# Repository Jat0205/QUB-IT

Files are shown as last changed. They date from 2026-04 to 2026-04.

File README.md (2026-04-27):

# QUB-IT
QUB-IT: A Quantum Bop It Game <br><br>
**Contributors:** <br>
Jessica Huang, UPitt EE<br>
Thomas Eble, UPitt EPhys<br>
Jannet Trabelsi, UPitt EPhys<br><br>
**Microcontroller:** <br> 
atmega328p <br><br>
**Programming Language:** <br>
C++<br><br>
**Pinout:** <br>
DO 0:Y ROT ENC <br>
DO 1: LED |+>  <br>
DO 2: X ROT ENC <br>
DO 3: LED |0> <br>
DO 4: AUDIO <br>
DO 5: AUDIO <br>
DO 6: LED |-> <br>
DO 7: Z ROT ENC <br>
DO 8: DEBUG LED <br>
DO 9: LED |1> <br>
DO 10: LED |i> <br>
DO 11: LED |-i> <br>
DO 12: <br>
DO 13: <br>
A0: BUTTON: Measure Z <br>
A1: BUTTON: Measure Y <br>
A2: BUTTON: Measure X <br>
A3:PHOTODIODE <br>
A4: LCD <br>
A5: LCD <br><br>

** Steps to reproduce our work:<br>
- Refer to the provided schematic to reproduce the work and test it on a breadboard first.<br>
- Order the PCB included through JLCPCB (we used their design rule check.<br>
- Order parts needed from digikey, amazon, thorlabs, and JBsuperstore (BOM is provided).<br>
- Solder PCB.<br>
- 3D print sphere, sphere stand, and remote enclosure (stl files included).<br>
- place the LEDs and photodiode in the sphere such as the LEDs on the same axis correspond to the same basis.<br>
- Connect the wires from the sphere to the wires soldered on the PCB (color code them for easier debugging)<br>
- Add the provided audio files in a micro SD card. <br>
- Attach the SD card to the DF player. <br>
- Connect a usbtiny Program the 6 pin area on the PCB and load the Qubit_Main.ino file into ardiino IDE, burn the bootloader, compile the program, export the compiled library, then program the board. if you have mac, open a terminal at folder then paste the following: avrdude -c usbtiny -p m328p -P usb -e -U flash:w:/Users/USERNAME/Documents/Arduino/Qubit_Main/build/arduino.avr.uno/Qubit_Main.ino.hex (please replace USER by your username).<br>
- Connect a 9 V battery and use the switch to turn on the toy. (the reset button can also be used to reset the game). <br>
- Enjoy Qub-it!<br>

Please note: there are multiple ino files to test individual functions and debug your PCB, such as LCD.ino, MEASURE_IT.ino, ROT_ENC.ino, STATE_TRANSITION.ino, audio_test.ino, and photodiode.ino. Each file tests an individual function.<br> 
The file named "finding_out_audio_names.ino" displays the file name recognized on the DF player on the LCD so you can go to the Qubit_Main.ino and edit this part with the corresponding numbers:<br>
// ================= DFPlayer TRACK MAP =================<br>
const int TRACK_INIT    = 7;<br>
const int TRACK_X       = 10;<br>
const int TRACK_Y       = 8;<br>
const int TRACK_Z       = 4;<br>
const int TRACK_MEASURE = 2;<br>
const int TRACK_STARTUP = 1;<br>

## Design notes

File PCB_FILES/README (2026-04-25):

Please submit this with JLCPCB to order a PCB for yourself.

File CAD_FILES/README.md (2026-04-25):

Please upload the SLT files to ultimaker CURA and choose your printer speed and support then export the gcode files then 3D print the enclosures.

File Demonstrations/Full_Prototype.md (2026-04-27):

Here is the link to the full prototype video: https://youtu.be/gmHKGlXtQ_0

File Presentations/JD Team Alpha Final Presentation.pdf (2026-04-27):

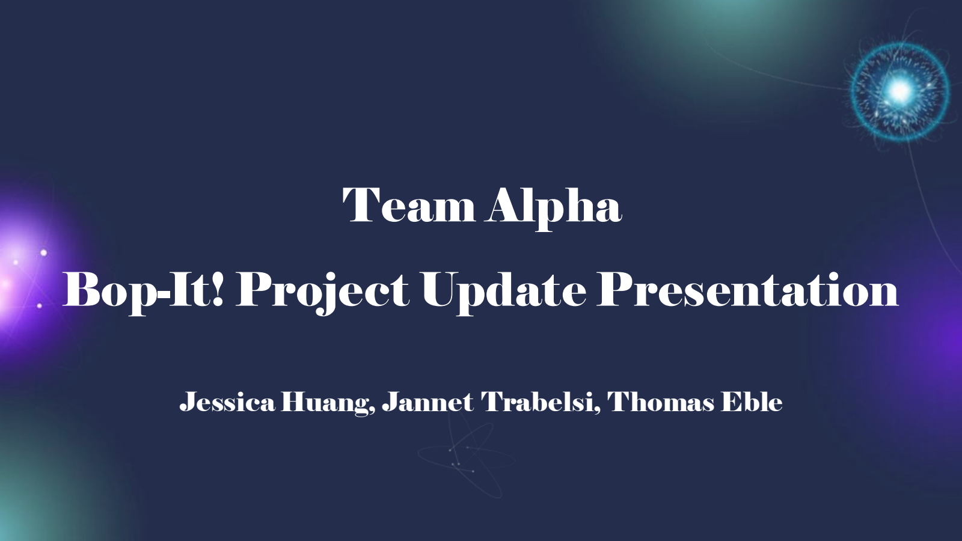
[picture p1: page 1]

# Team Alpha

# Bop-It! Project Update Presentation

### Jessica Huang, Jannet Trabelsi, Thomas Eble

# Our version of Bop-It….Qub-It!

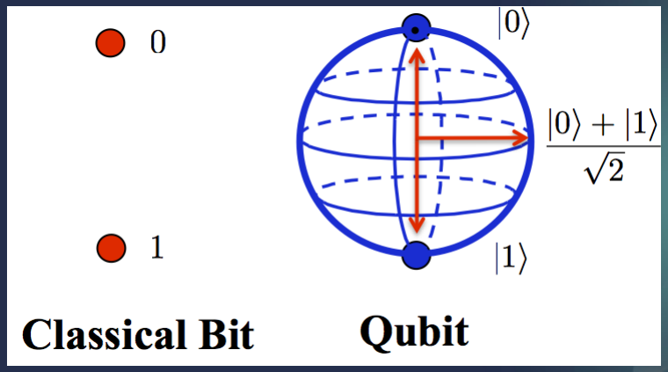
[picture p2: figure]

Brief review of how a qubit works:

A qubit is like a spinning arrow (or coin):

- - Unlike a normal bit, it can be 0, 1, 0r both at

once (superposition)

- Quantum gates rotate that arrow to control the

qubit’s state in 3D space in the x,y,z axes.

- When you measure, it collapses to either 0 or 1.
- Over time, noise can interfere, causing

decoherence

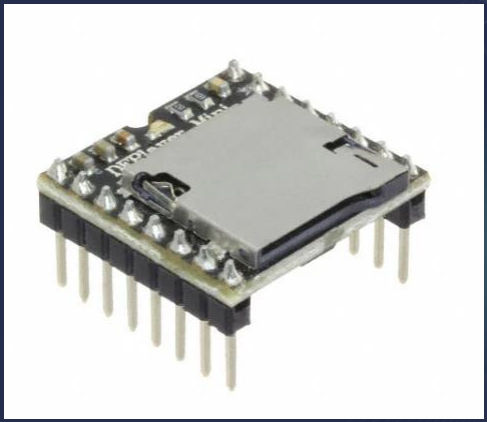
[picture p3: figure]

# Status Update

The DF-Player draws too much

current!

Our (2nd) PCB does not have the

proper power distribution to

handle high current draw.

A DF boot failure causes the rest

of our code to not function

properly

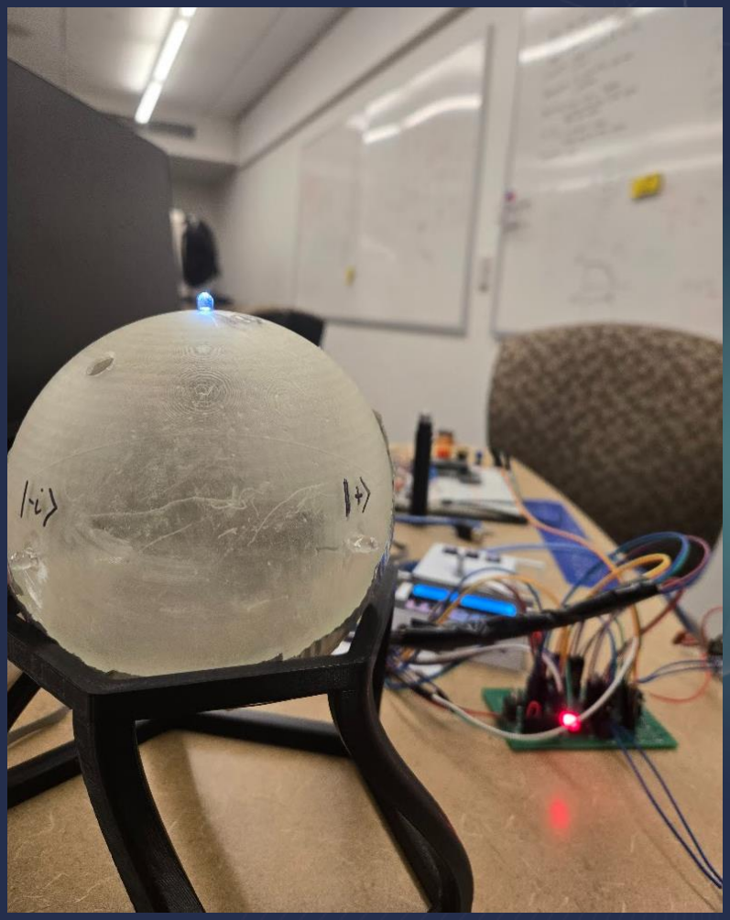
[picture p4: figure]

# Status Update

Our enclosure demonstrates gating and

measurement state transition functionality

However, our complete QUB-IT protocol only

functions at the breadboard phase!

# Future Work

- Third PCB redesign with appropriate power distribution

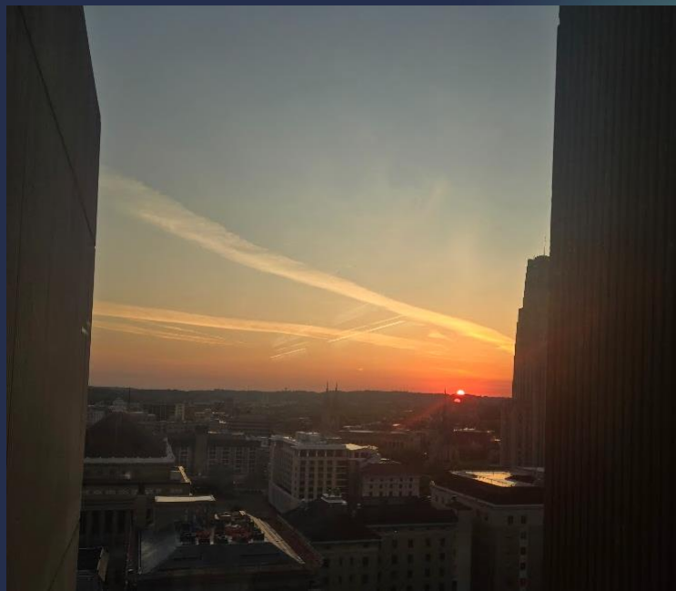
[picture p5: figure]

- Further enclosure iterations
- More ergonomic
- Fits new PCB
- Snap-fit
- Resin print lid
- New sphere with better diameter tolerance

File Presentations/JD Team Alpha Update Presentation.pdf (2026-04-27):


# Team Alpha

# Bop-It! Project Update Presentation

Jessica Huang, Jannet Trabelsi, Thomas Eble

What is a Qubit? | Z Measurement

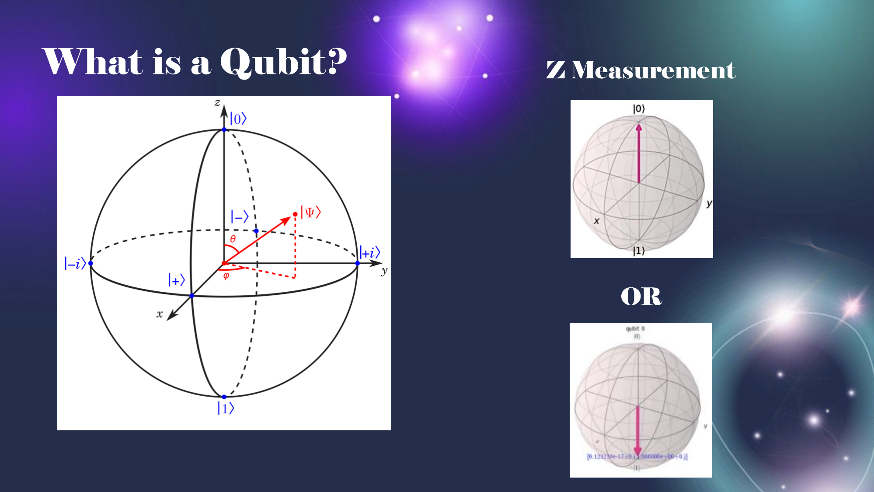
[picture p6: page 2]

OR

## What is a Qubit?

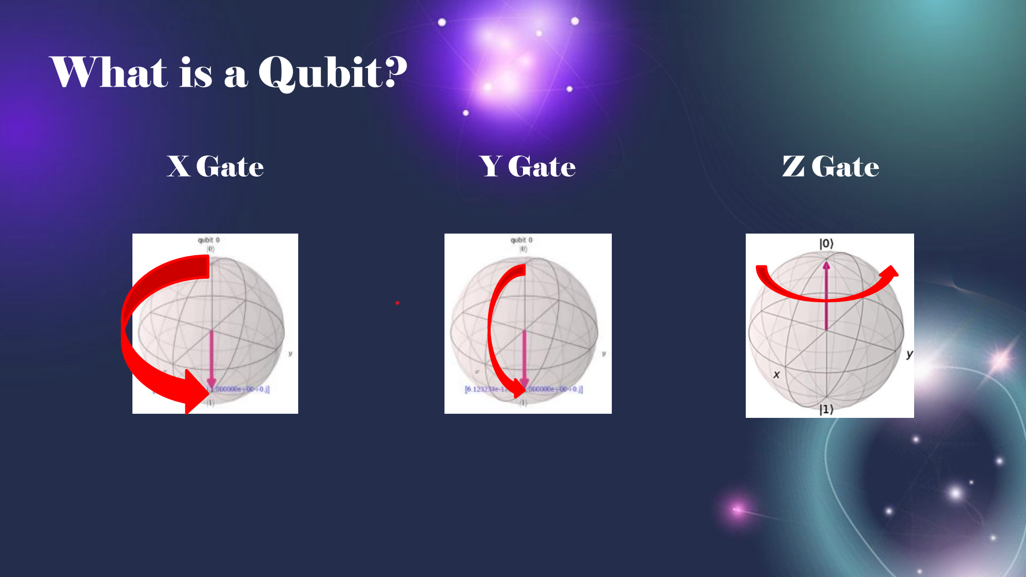
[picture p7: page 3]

X Gate | Y Gate | Z Gate

## Our version of Bop-It….Qub-It!

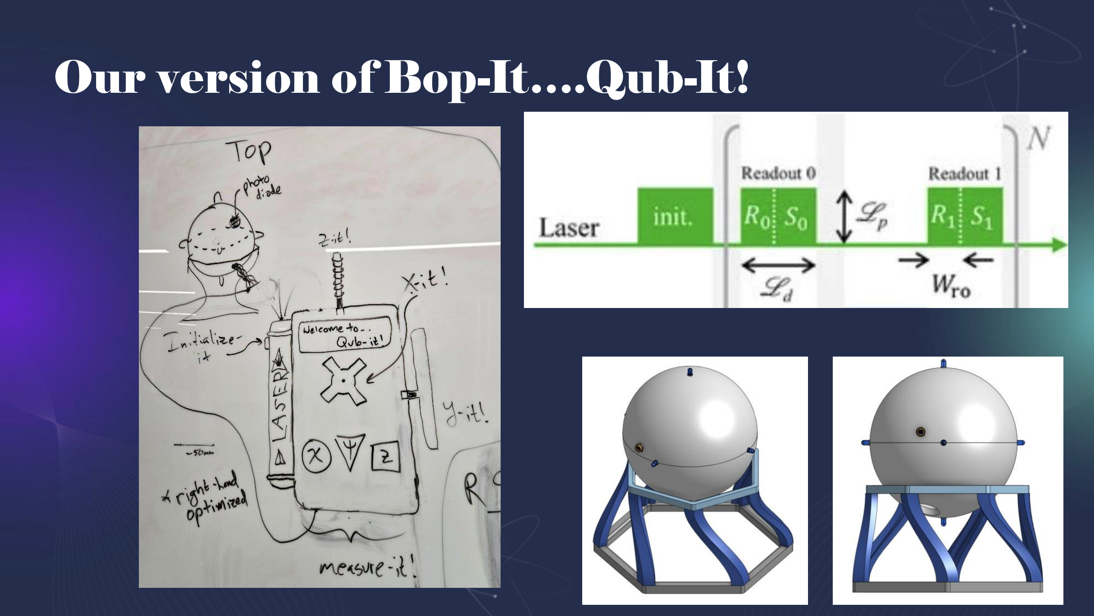
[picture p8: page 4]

## Progress (Start to Now)

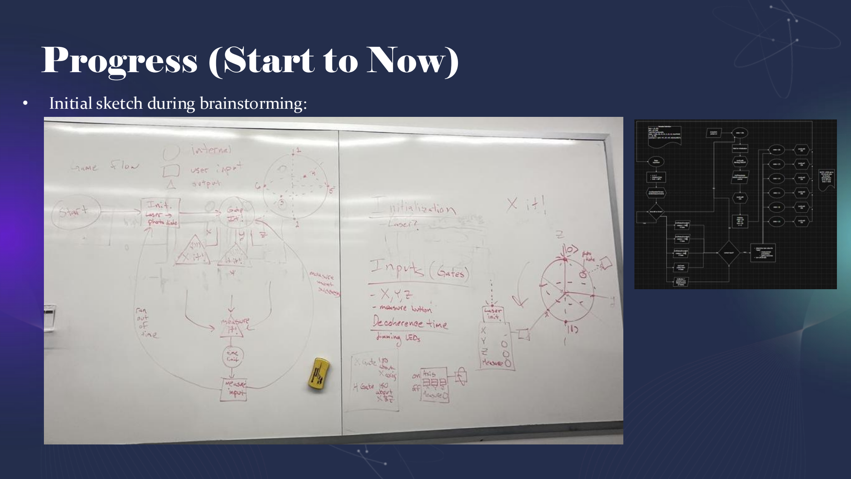
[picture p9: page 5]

- Initial sketch during brainstorming:

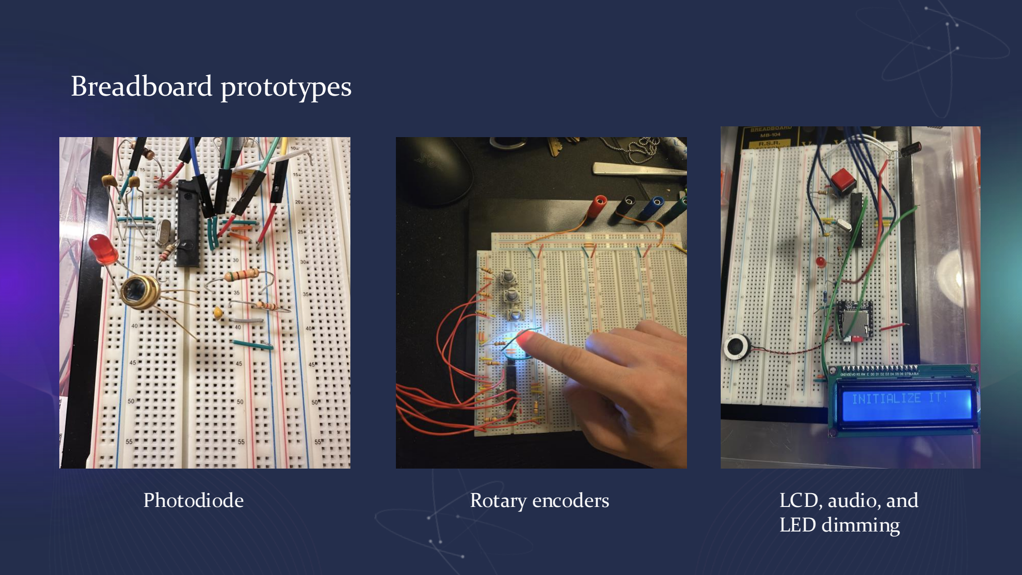
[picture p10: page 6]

Photodiode | Rotary encoders

Breadboard prototypes

LCD, audio, and
LED dimming

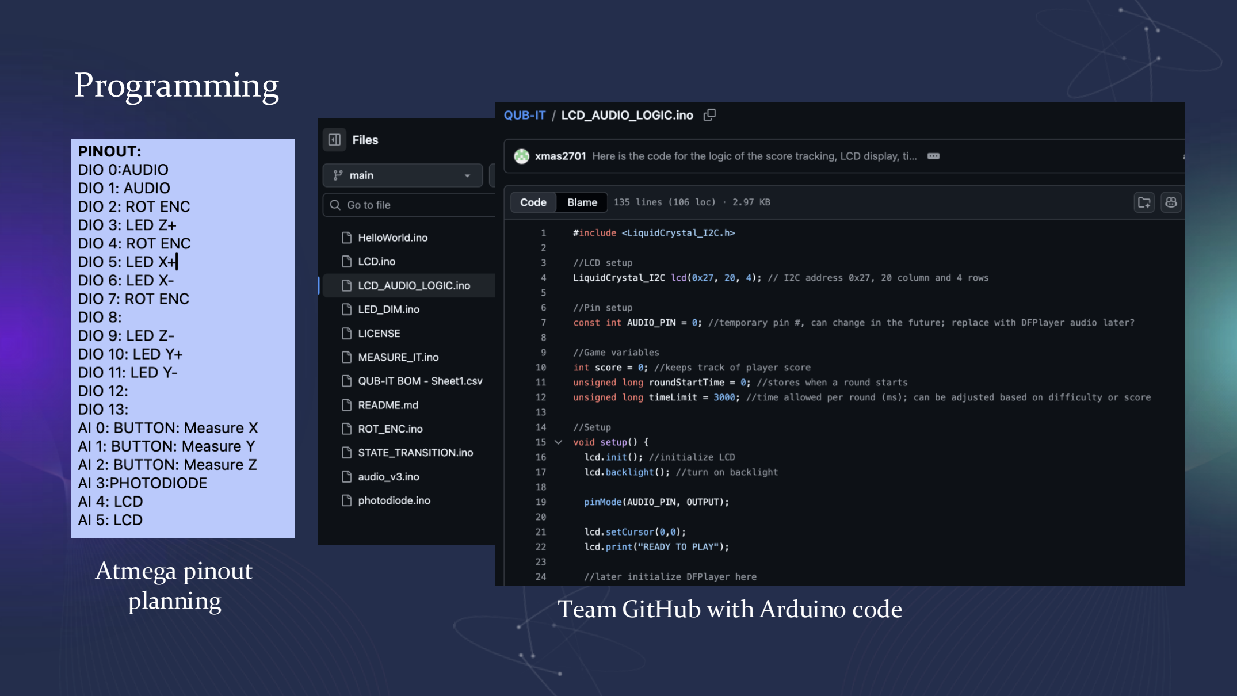
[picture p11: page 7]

Atmega pinout
planning | Team GitHub with Arduino code

Programming

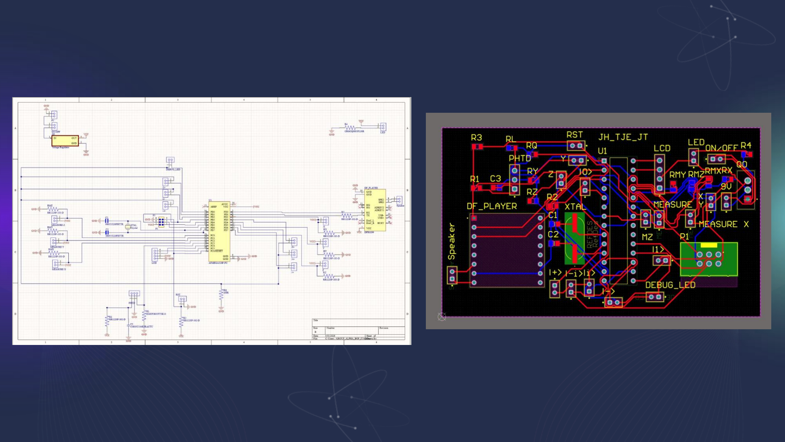
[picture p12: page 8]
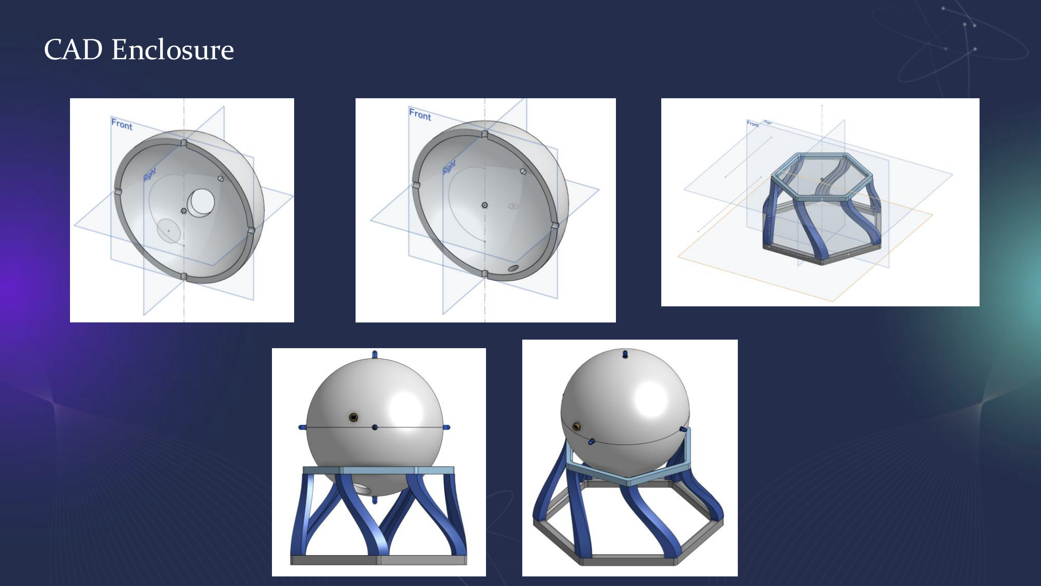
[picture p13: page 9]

CAD Enclosure

## What we still need to work on…

- Design PCB enclosure/main Bop-It toy
- Combine gating logic with dimming logic and Bop-It game functionality
- Solder PCB
- Assemble QUB-IT!
- If time permitting...
- Enclosure improvements: better aesthetics, stronger plastic/resin
- Addition of an H gate and the various code and board adjustments that come with it

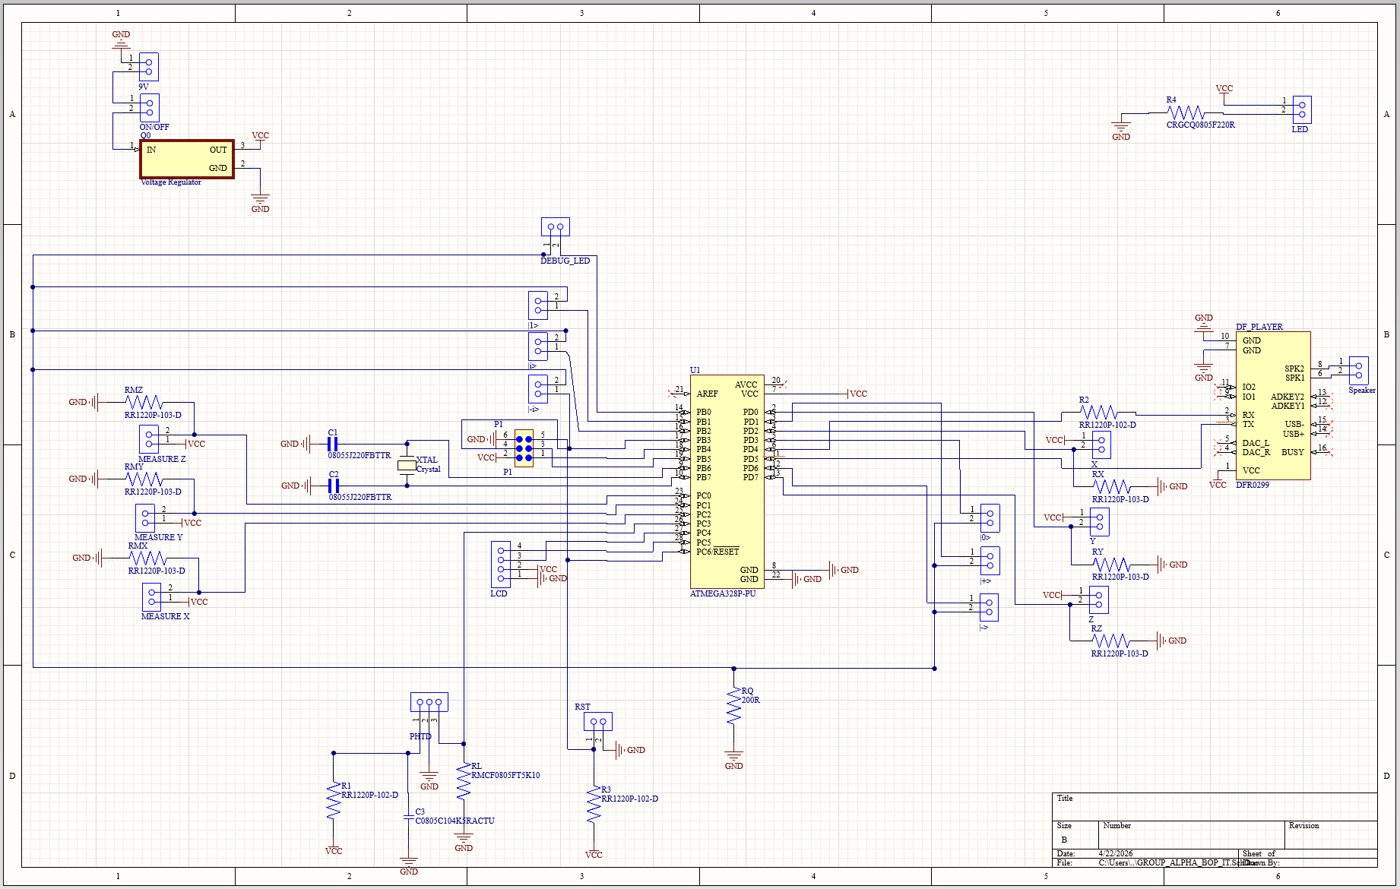
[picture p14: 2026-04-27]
PCB_FILES/SCHEMATIC.png

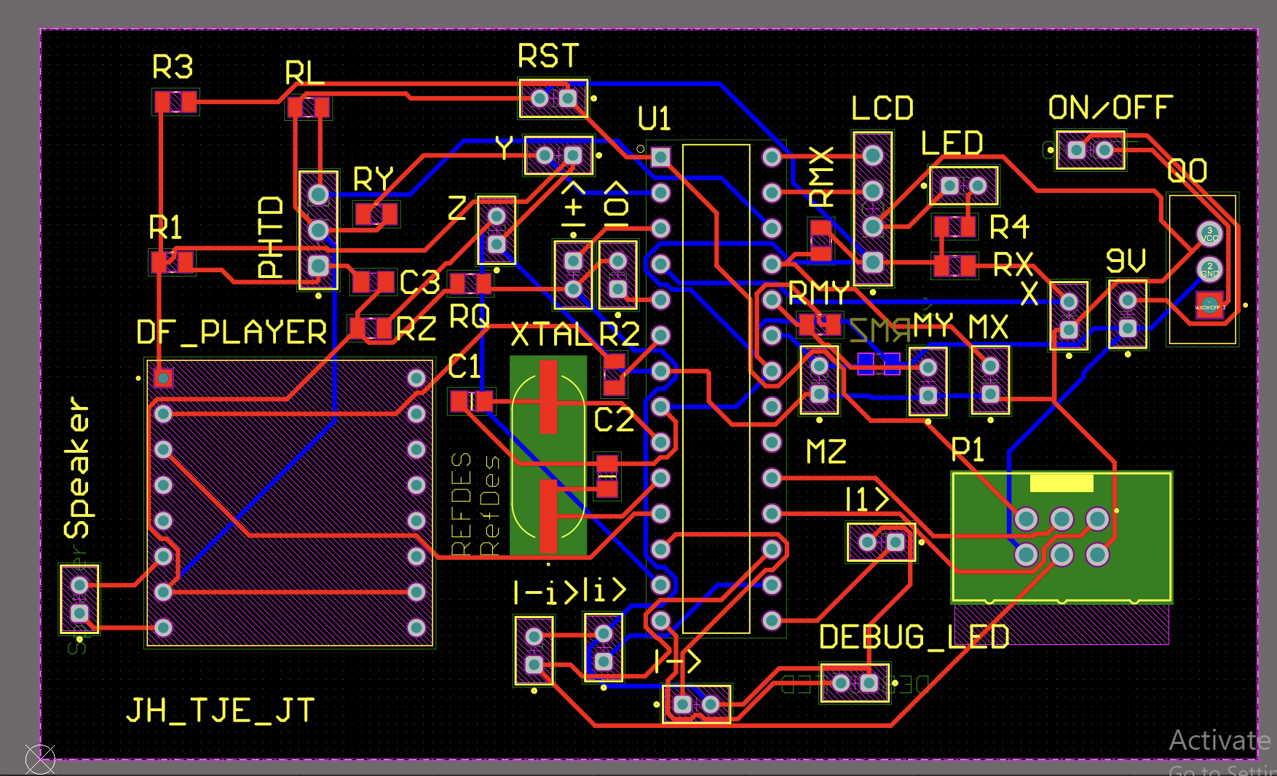
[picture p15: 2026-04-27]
PCB_FILES/PCB_Screenshot.png

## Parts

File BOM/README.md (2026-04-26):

Please order the following: <br>
- Photodiode: https://www.thorlabs.com/item/FDS100 $17.55 <br>
- LCD: https://jbsuperstore.com/products/Display-20x4-LCD-Screen-I2C-p799723774 $9.98<br>
- USBtinyISP Programmer: https://everymarket.com/products/usbtiny-usbtinyisp-avr-usb-tiny-isp-programmer-bootloader-with-programming-cable <br>
- Laser pointer: https://www.amazon.com/Advanced-Long-Range-Laser-Pointer-Power/dp/B0DP9G71M2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 $9.98<br>
- DF player: https://jbsuperstore.com/products/DFPlayer-Mini-MP3-Player-TF-MicroSD-card-compatible-p777890314 $5.90 <br>
- Dijikey: (please upload the CSV to dijikey and order the parts) :$41.75<br>
Total Cost = $17.55+ $9.98+ $9.98 + $5.90+ $98.10 = $141.51 <br>

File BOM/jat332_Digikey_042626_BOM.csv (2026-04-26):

Index | Quantity | Part Number | Manufacturer Part Number | Description | Customer Reference | Available | Backorder | Unit Price | Extended Price USD
1 | 1 | 732-5394-ND | 61200621621 | CONN HEADER VERT 6POS 2.54MM | jat332 | 1 | 0 | 0.48000 | 0.48
2 | 1 | 300-6134-1-ND | HCM4916000000ABJT | CRYSTAL 16.0000MHZ 18PF SMD | jat332 | 1 | 0 | 0.44000 | 0.44
3 | 2 | 478-11911-1-ND | 08055J220FBTTR | CAP THIN FILM 22PF 50V 0805 | jat332 | 2 | 0 | 1.90000 | 3.80
4 | 1 | 399-C0805C104K5RACTUCT-ND | C0805C104K5RACTU | CAP CER 0.1UF 50V X7R 0805 | jat332 | 1 | 0 | 0.13000 | 0.13
5 | 3 | RMCF0805FT5K10CT-ND | RMCF0805FT5K10 | RES 5.1K OHM 1% 1/8W 0805 | jat332 | 3 | 0 | 0.10000 | 0.30
6 | 1 | RR12P10.0KDCT-ND | RR1220P-103-D | RES SMD 10K OHM 0.5% 1/10W 0805 | jat332 | 1 | 0 | 0.10000 | 0.10
7 | 1 | RR12P1.0KDCT-ND | RR1220P-102-D | RES SMD 1K OHM 0.5% 1/10W 0805 | jat332 | 1 | 0 | 0.10000 | 0.10
8 | 1 | ATMEGA328-PU-ND | ATMEGA328-PU | IC MCU 8BIT 32KB FLASH 28DIP | jat332 | 1 | 0 | 2.63000 | 2.63
9 | 8 | 160-1142-ND | LTL-4231N | LED GREEN DIFFUSED T/H | jat332 | 8 | 0 | 0.15000 | 1.20
10 | 4 | EG2041-ND | PS1057ABLK | SWITCH PUSH SPST-NO 1A 125V | jat332 | 4 | 0 | 1.76000 | 7.04
11 | 1 | RA11131100-ND | RA11131100 | SWITCH ROCKER SPST 10A 125V | jat332 | 1 | 0 | 0.64000 | 0.64
12 | 1 | 497-1443-5-ND | L7805CV | IC REG LINEAR 5V 1.5A TO220 | jat332 | 1 | 0 | 0.50000 | 0.50
13 | 1 | P687-ND | 6LF22XWA/B | BATTERY ALKALINE 9V | jat332 | 1 | 0 | 2.32000 | 2.32
14 | 1 | 36-233-ND | 233 | BATT CONNECTOR SNAP 9V 6" LEADS | jat332 | 1 | 0 | 0.58000 | 0.58
15 | 1 | 433-1150-ND | SP-3605 | SPEAKER 8OHM 1W TOP PORT 90DB | jat332 | 1 | 0 | 3.62000 | 3.62
16 | 1 | 2084-SQF-MSDS1-256M-21E-ND | SQF-MSDS1-256M-21E | SQF MICRO SD C6 SLC 256M, 1CH (- | jat332 | 0 | 1 | 9.98000 | 9.98
17 | 1 | 2057-ICM-328-1-GT-HT-ND | ICM-328-1-GT-HT | MACHINE PIN SOCKET, IC, DIP, 28P | jat332 | 1 | 0 | 1.28000 | 1.28
18 | 1 | 72-T0051404699-ND | T0051404699 | WSW SCN M1 SN0,6CU0,05NI3,5% | jat332 | 1 | 0 | 21.82000 | 21.82
19 | 1 | K617-ND | R30G-0100 | WIRE WW 30AWG PVDF GREEN 100' | jat332 | 1 | 0 | 24.86000 | 24.86
20 | 3 | PEC11R-4220K-S0024-ND | PEC11R-4220K-S0024 | ENCODER INCREM QUAD VERT PC PIN | jat332 | 3 | 0 | 2.27000 | 6.81

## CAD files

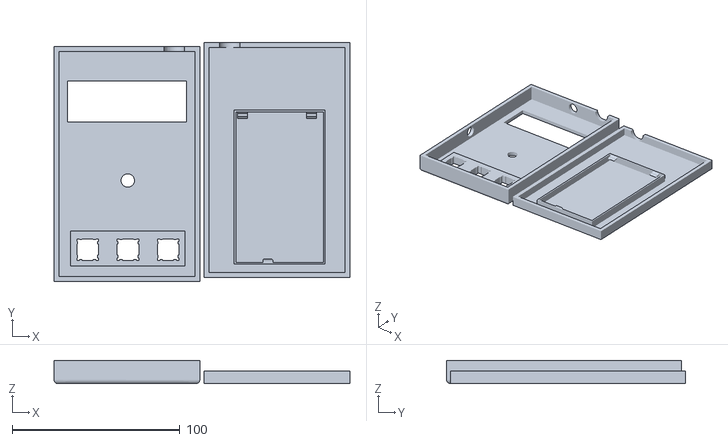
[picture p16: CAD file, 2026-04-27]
CAD_FILES/QUBIT_main_v9.stl
176.5 x 142.5 x 14.0

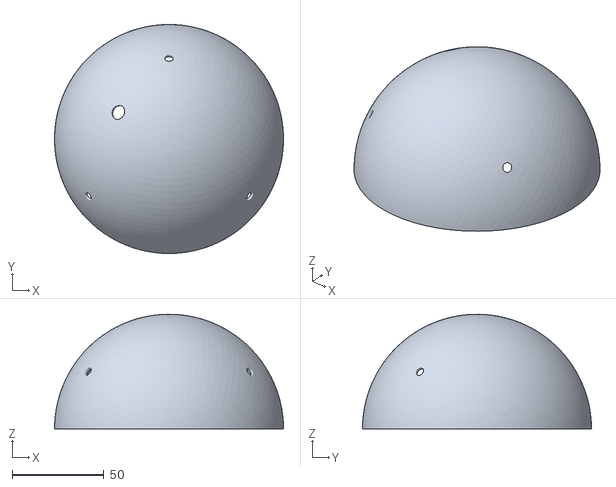
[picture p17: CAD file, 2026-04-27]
CAD_FILES/QUBIT_pdsphere_v3.stl
125.0 x 125.0 x 62.5

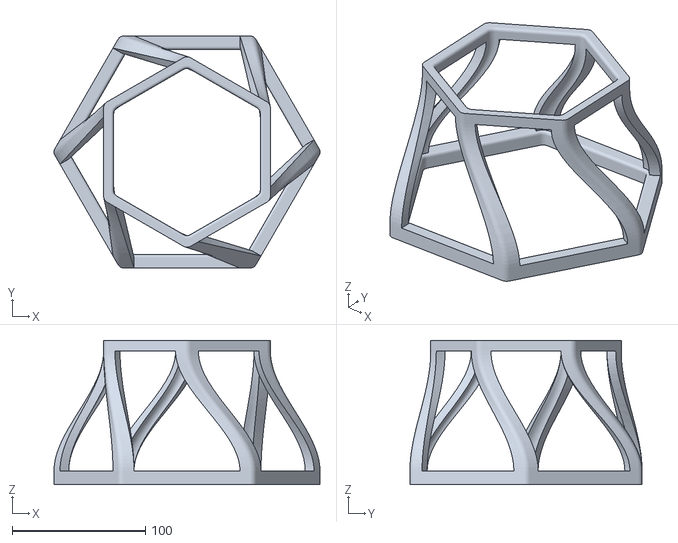
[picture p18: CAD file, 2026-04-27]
CAD_FILES/QUBIT_stand_v1.stl
199.7 x 174.3 x 108.5

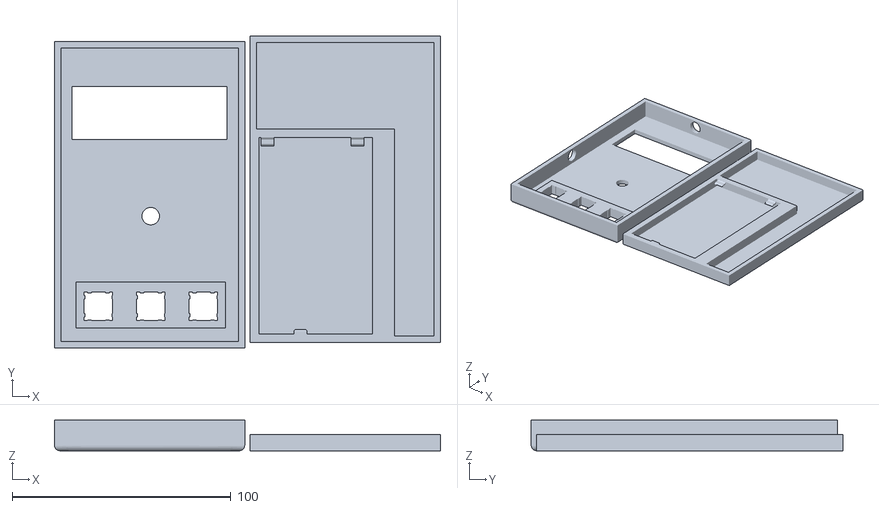
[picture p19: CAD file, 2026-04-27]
CAD_FILES/QUBIT_Lid_v5.stl
176.5 x 142.5 x 14.0

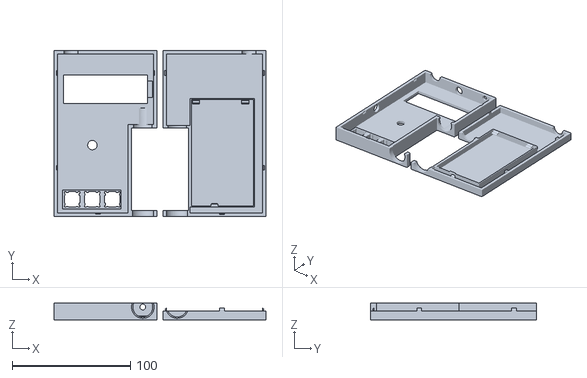
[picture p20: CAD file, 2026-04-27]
CAD_FILES/QUBIT_enclosure_v20.stl
179.0 x 140.0 x 14.0

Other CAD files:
CAD_FILES/QUBIT_csphere_v3.stl

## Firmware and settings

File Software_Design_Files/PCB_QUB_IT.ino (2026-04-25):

// ================================================================
//  QUB-IT  —  A Quantum Bop-It Game
// ================================================================

#include "Arduino.h"
#include <LiquidCrystal_I2C.h>
#include "DFRobotDFPlayerMini.h"

// ================= SOFT SERIAL FOR DFPLAYER =================
#if (defined(ARDUINO_AVR_UNO) || defined(ESP8266))
#include <SoftwareSerial.h>
SoftwareSerial softSerial(/*rx =*/4, /*tx =*/5);
#define FPSerial softSerial
#else
#define FPSerial Serial1
#endif

DFRobotDFPlayerMini myDFPlayer;

// ================= LCD =================
LiquidCrystal_I2C lcd(0x27, 20, 4);

// ================= PIN DEFINITIONS =================
const int ROTENCX    = 2;
const int ROTENCY    = 0;
const int ROTENCZ    = 7;
const int DEBUGLED   = 8;
const int PHOTODIODE = A3;
const int MEASUREX   = A2;
const int MEASUREY   = A1;
const int MEASUREZ   = A0;

const int LED_PINS[6] = {
  3,   // index 0 → |0>   (PWM)
  9,   // index 1 → |1>   (PWM)
  1,   // index 2 → |+>   (digital only)
  6,   // index 3 → |->   (PWM)
  10,  // index 4 → |i>   (PWM)
  11   // index 5 → |-i>  (PWM)
};

// ================= QUBIT PHYSICS ENGINE =================
int qubitState = 0;

const int NUM_OPS    = 8;
const int NUM_STATES = 6;
const int state_transition[NUM_OPS][NUM_STATES] = {
  {0, 0, 0, 0, 0, 0},
  {1, 0, 2, 3, 5, 4},
  {1, 0, 3, 2, 4, 5},
  {0, 1, 3, 2, 5, 4},
  {2, 3, 0, 1, 5, 4},        // H (unused)
  {-1, -1, 2, 3, -1, -1},
  {-2, -2, -2, -2, 4, 5},
  {0, 1, -3, -3, -3, -3},
};

int collapse_it(int state) {
  int coin = TCNT0 & 1;
  if (state == -1) return (coin == 0) ? 2 : 3;
  if (state == -2) return (coin == 0) ? 4 : 5;
  if (state == -3) return (coin == 0) ? 0 : 1;
  return state;
}

// ================= ENCODER GLOBALS =================
volatile int encX = 0, encY = 0, encZ = 0;
int lastStateX = LOW, lastStateY = LOW, lastStateZ = LOW;

// ================= GAME STATE MACHINE =================
enum GameState {
  GS_IDLE,
  GS_COMMAND,
  GS_WAIT_INPUT,
  GS_SUCCESS,
  GS_GAME_OVER
};
GameState gameState = GS_IDLE;

enum Command {
  CMD_INIT,
  CMD_X,
  CMD_Y,
  CMD_Z,
  CMD_MEASURE
};
Command currentCmd = CMD_INIT;

// Forward declarations
//void playCommand(Command cmd);
bool checkForWrongInput(Command cmd);
bool checkCorrectInput(Command cmd);
Command pickRandomCommand();
const char* commandText(Command cmd);

int  score           = 0;
int  dim_value       = 255;
bool ledOn           = false;
int  currentLedPin   = -1;

unsigned long roundStart    = 0;
unsigned long roundDuration = 10000;
const unsigned long MIN_ROUND_TIME = 2500;

const int ENCODER_THRESHOLD = 5;

// ================= DFPlayer TRACK MAP =================
const int TRACK_INIT    = 7;
const int TRACK_X       = 10;
const int TRACK_Y       = 8;
const int TRACK_Z       = 4;
const int TRACK_MEASURE = 2;
const int TRACK_STARTUP = 1;

// ================= DEBUG LED =================
void flashDebugLed() {
  digitalWrite(DEBUGLED, HIGH);
  delay(80);
  digitalWrite(DEBUGLED, LOW);
}

// ================= LED HELPERS =================
void ledWrite(int pin, int value) {
  if (pin == 1) {
    digitalWrite(pin, value > 127 ? HIGH : LOW);
  } else {
    analogWrite(pin, value);
  }
}

void allLedsOff() {
  for (int i = 0; i < 6; i++) {
    ledWrite(LED_PINS[i], 0);
  }
  ledOn = false;
  currentLedPin = -1;
}

void showQubitLed() {
  allLedsOff();
  currentLedPin = LED_PINS[qubitState];
  dim_value = 255;
  ledWrite(currentLedPin, 255);
  ledOn = true;
}

void dimLed() {
  if (!ledOn || currentLedPin < 0) return;
  unsigned long elapsed = millis() - roundStart;
  if (elapsed >= roundDuration) {
    dim_value = 0;
  } else {
    dim_value = map(elapsed, 0, roundDuration, 255, 0);
  }
  ledWrite(currentLedPin, dim_value);
  if (dim_value == 0) ledOn = false;
}

// ================= ENCODER POLLING =================
void pollEncoders() {
  int cx = digitalRead(ROTENCX);
  int cy = digitalRead(ROTENCY);
  int cz = digitalRead(ROTENCZ);

  if (cx == HIGH && lastStateX == LOW) encX++;
  lastStateX = cx;

  if (cy == HIGH && lastStateY == LOW) encY++;
  lastStateY = cy;

  if (cz == HIGH && lastStateZ == LOW) encZ++;
  lastStateZ = cz;
}

void resetEncoders() {
  encX = 0; encY = 0; encZ = 0;
}

// ================= SPEAKER =================
/*void playCommand(Command cmd) {
  switch (cmd) {
    case CMD_INIT:    myDFPlayer.play(TRACK_INIT);    break;
    case CMD_X:       myDFPlayer.play(TRACK_X);       break;
    case CMD_Y:       myDFPlayer.play(TRACK_Y);       break;
    case CMD_Z:       myDFPlayer.play(TRACK_Z);       break;
    case CMD_MEASURE: myDFPlayer.play(TRACK_MEASURE); break;
  }
}*/

// ================= LCD HELPERS =================
void lcdShowCommand(const char* text) {
  lcd.clear();
  lcd.setCursor(0, 0);
  lcd.print(text);
}

// ================= INPUT DETECTION =================
bool checkForWrongInput(Command cmd) {
  int mx = digitalRead(MEASUREX);
  int my = digitalRead(MEASUREY);
  int mz = digitalRead(MEASUREZ);
  int photo = analogRead(PHOTODIODE);
  bool laserHit = (photo >= 512);

  switch (cmd) {
    case CMD_INIT:
      if (mx == HIGH || my == HIGH || mz == HIGH) return true;
      if (encX > 2 || encY > 2 || encZ > 2) return true;
      break;
    case CMD_X:
      if (mx == HIGH || my == HIGH || mz == HIGH) return true;
      if (laserHit) return true;
      if (encY > ENCODER_THRESHOLD || encZ > ENCODER_THRESHOLD) return true;
      break;
    case CMD_Y:
      if (mx == HIGH || my == HIGH || mz == HIGH) return true;
      if (laserHit) return true;
      if (encX > ENCODER_THRESHOLD || encZ > ENCODER_THRESHOLD) return true;
      break;
    case CMD_Z:
      if (mx == HIGH || my == HIGH || mz == HIGH) return true;
      if (laserHit) return true;
      if (encX > ENCODER_THRESHOLD || encY > ENCODER_THRESHOLD) return true;
      break;
    case CMD_MEASURE:
      if (laserHit) return true;
      if (encX > 2 || encY > 2 || encZ > 2) return true;
      break;
  }
  return false;
}

bool checkCorrectInput(Command cmd) {
  switch (cmd) {
    case CMD_INIT: {
      int photo = analogRead(PHOTODIODE);
      if (photo >= 512) {
        qubitState = state_transition[0][qubitState];
        return true;
      }
      return false;
    }
    case CMD_X:
      if (encX >= ENCODER_THRESHOLD) {
        qubitState = state_transition[1][qubitState];
        return true;
      }
      return false;
    case CMD_Y:
      if (encY >= ENCODER_THRESHOLD) {
        qubitState = state_transition[2][qubitState];
        return true;
      }
      return false;
    case CMD_Z:
      if (encZ >= ENCODER_THRESHOLD) {
        qubitState = state_transition[3][qubitState];
        return true;
      }
      return false;
    case CMD_MEASURE: {
      int mx = digitalRead(MEASUREX);
      int my = digitalRead(MEASUREY);
      int mz = digitalRead(MEASUREZ);
      if (mx == HIGH) {
        qubitState = state_transition[5][qubitState];
        qubitState = collapse_it(qubitState);
        return true;
      }
      if (my == HIGH) {
        qubitState = state_transition[6][qubitState];
        qubitState = collapse_it(qubitState);
        return true;
      }
      if (mz == HIGH) {
        qubitState = state_transition[7][qubitState];
        qubitState = collapse_it(qubitState);
        return true;
      }
      return false;
    }
  }
  return false;
}

// ================= COMMAND GENERATION =================
Command pickRandomCommand() {
  int r = random(0, 5);
  switch (r) {
    case 0:  return CMD_INIT;
    case 1:  return CMD_X;
    case 2:  return CMD_Y;
    case 3:  return CMD_Z;
    default: return CMD_MEASURE;
  }
}

const char* commandText(Command cmd) {
  switch (cmd) {
    case CMD_INIT:    return "INITIALIZE IT!";
    case CMD_X:       return "X IT!";
    case CMD_Y:       return "Y IT!";
    case CMD_Z:       return "Z IT!";
    case CMD_MEASURE: return "MEASURE IT!";
  }
  return "";
}

// ================================================================
//  SETUP
// ================================================================
void setup() {
  lcd.init();
  lcd.backlight();
  lcd.clear();
  lcd.setCursor(0, 0);
  lcd.print("QUB-IT");
  lcd.setCursor(0, 1);
  lcd.print("Point laser to start");

  FPSerial.begin(9600);
  /*if (!myDFPlayer.begin(FPSerial, true, true)) {
    lcd.clear();
    lcd.print("DFPlayer FAIL");
    while (true);
  }
  myDFPlayer.setTimeOut(500);
  myDFPlayer.volume(30);
  myDFPlayer.EQ(DFPLAYER_EQ_NORMAL);
  myDFPlayer.outputDevice(DFPLAYER_DEVICE_SD);
  myDFPlayer.play(TRACK_STARTUP);*/

  pinMode(ROTENCX, INPUT);
  pinMode(ROTENCY, INPUT);
  pinMode(ROTENCZ, INPUT);
  pinMode(DEBUGLED, OUTPUT);
  pinMode(MEASUREX, INPUT);
  pinMode(MEASUREY, INPUT);
  pinMode(MEASUREZ, INPUT);
  for (int i = 0; i < 6; i++) {
    pinMode(LED_PINS[i], OUTPUT);
    ledWrite(LED_PINS[i], 0);
  }

  lastStateX = digitalRead(ROTENCX);
  lastStateY = digitalRead(ROTENCY);
  lastStateZ = digitalRead(ROTENCZ);
  randomSeed(analogRead(A5));

  gameState = GS_IDLE;
  qubitState = 0;
  score = 0;
}

// ================================================================
//  MAIN LOOP
// ================================================================
void loop() {
  pollEncoders();

  switch (gameState) {

    case GS_IDLE: {
      int photo = analogRead(PHOTODIODE);
      if (photo >= 512) {
        flashDebugLed();
        qubitState = 0;
        score = 0;
        roundDuration = 10000;
        allLedsOff();
        showQubitLed();
        score++;
        gameState = GS_SUCCESS;
      }
      break;
    }

    case GS_COMMAND: {
      currentCmd = pickRandomCommand();
      lcdShowCommand(commandText(currentCmd));
      //playCommand(currentCmd);
      resetEncoders();
      roundStart = millis();
      showQubitLed();
      gameState = GS_WAIT_INPUT;
      break;
    }

    case GS_WAIT_INPUT: {
      if (millis() - roundStart >= roundDuration) {
        gameState = GS_GAME_OVER;
        break;
      }
      dimLed();
      if (checkForWrongInput(currentCmd)) {
        flashDebugLed();
        gameState = GS_GAME_OVER;
        break;
      }
      if (checkCorrectInput(currentCmd)) {
        flashDebugLed();
        gameState = GS_SUCCESS;
      }
      break;
    }

    case GS_SUCCESS: {
      showQubitLed();
      lcd.clear();
      lcd.setCursor(0, 0);
      lcd.print("GOOD!");
      lcd.setCursor(0, 1);
      lcd.print("Score: ");
      lcd.print(score);

      if (score >= 99) {
        lcd.clear();
        lcd.setCursor(0, 0);
        lcd.print("VICTORY!");
        lcd.setCursor(0, 1);
        lcd.print("Final Score: 99");
        lcd.setCursor(0, 2);
        lcd.print("You are a quantum");
        lcd.setCursor(0, 3);
        lcd.print("master!");
        gameState = GS_GAME_OVER;
        break;
      }

      if (roundDuration > MIN_ROUND_TIME) {
        roundDuration -= 500;
        if (roundDuration < MIN_ROUND_TIME) {
          roundDuration = MIN_ROUND_TIME;
        }
      }

      delay(400);
      score++;
      gameState = GS_COMMAND;
      break;
    }

    case GS_GAME_OVER: {
      allLedsOff();
      lcd.clear();
      lcd.setCursor(0, 0);
      lcd.print("GAME OVER");
      lcd.setCursor(0, 1);
      lcd.print("Score: ");
      lcd.print(score);
      lcd.setCursor(0, 2);
      lcd.print("Laser to restart");

      while (true) {
        int photo = analogRead(PHOTODIODE);
        if (photo >= 512) {
          flashDebugLed();
          delay(500);
          break;
        }
      }

      qubitState = 0;
      score = 0;
      roundDuration = 10000;
      resetEncoders();
      allLedsOff();
      showQubitLed();
      score++;
      gameState = GS_SUCCESS;
      break;
    }
  }
}

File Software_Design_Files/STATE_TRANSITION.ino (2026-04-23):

// global variable definition
int r = 0; //number of rounds successfully passed
const int DIFFICULTY = 0; //difficulty integer which, when modified, changes the rate at which the game gets faster (when it is zero, every round is the same length)
int qubitState = 0; //current state of the qubit

//STATE TRANSITION LOOKUP TABLE
// transition[operation][current_state] = new_state
// operations:   0=intialize, 1=apply_x_gate, 2=apply_y_gate, 3=apply_z_gate 4=apply_h_gate, 5=perform_x_measurement, 6=perform_y_measurement, 7=perform_z_measurement
// States:  0=|0>, 1=|1>, 2=|+>, 3=|->, 4=|i>, 5=|-i>
const int NUM_OPS = 8;
const int NUM_STATES = 6;
const int state_transition[NUM_OPS][NUM_STATES] = {
  {0, 0, 0, 0, 0, 0},  // INIT: always |0>
  {1, 0, 2, 3, 5, 4},  // X: swap 0↔1, swap 4↔5, keep 2,3
  {1, 0, 3, 2, 4, 5},  // Y: swap 0↔1, swap 2↔3, keep 4,5
  {0, 1, 3, 2, 5, 4},  // Z: keep 0,1, swap 2↔3, swap 4↔5
  {2, 3, 0, 1, 5, 4},  // H: swap 0↔2, swap 1↔3, swap 4↔5
  {-1, -1, 2, 3, -1, -1},  // XMEAS: every -1 needs sep. function to collapse to 2 or 3
  {-2, -2, -2, -2, 4, 5},  // YMEAS: every -2 needs sep. function to collapse to 4 or 5
  {0, 1, -3, -3, -3, -3},  // ZMEAS: every -3 needs sep. function to collapse to 1 or 0
};


bool LEDS[NUM_STATES] = {false, false, false, false, false, false};
bool INIT_LED = false; //LED on the controller that flashes whn turned on and held on when qubit is initialized

//rot_enc globals
int x = 0;
int y = 0;
int z = 0;
int lastStateX = LOW;
int lastStateY = LOW;
int lastStateZ = LOW;

int coin = 0;


void setup() {
  pinMode(2, INPUT); //rot_encX
  pinMode(0, INPUT); //rot_encY
  pinMode(7, INPUT); //rot_encZ
  pinMode(8, OUTPUT);//output LED to verify rot_enc pulsing
  pinMode(A2, INPUT); //measure x button
  pinMode(A1, INPUT); //measure y button
  pinMode(A0, INPUT); //measure z button
  pinMode(3, OUTPUT); //|0> output
  pinMode(9, OUTPUT); //|1> output
  pinMode(1, OUTPUT); //|+> output
  pinMode(6, OUTPUT); //|-> output
  pinMode(10, OUTPUT); //|i> output
  pinMode(11, OUTPUT); //|-i> output
  lastStateX = digitalRead(2);
  lastStateY = digitalRead(0);
  lastStateZ = digitalRead(7);
  qubitState = 0;
}

void loop() {
  //rot_encX, Y, and Z, input detection
  detect_rotation();

  //state transitions for x, y, and z gate inputs
  detect_Xgate();
  detect_Ygate();
  detect_Zgate();

  //state transitions for x, y, and z measure inputs
  detect_Xmeasure();
  detect_Ymeasure();
  detect_Zmeasure();

  diode_output(qubitState);
}

void detect_Xmeasure(){
  int measureX = digitalRead(A2);
  if(measureX == HIGH){
    qubitState = state_transition[5][qubitState];
    qubitState = collapse_it(qubitState);
    digitalWrite(8, HIGH);
    delay(1000);
    digitalWrite(8, LOW);
  }
}

void detect_Ymeasure(){
  int measureY = digitalRead(A1);
  if(measureY == HIGH){
    qubitState = state_transition[6][qubitState];
    qubitState = collapse_it(qubitState);
    digitalWrite(8, HIGH);
    delay(1000);
    digitalWrite(8, LOW);
  }
}

void detect_Zmeasure(){
  int measureZ = digitalRead(A0);
  if(measureZ == HIGH){
    qubitState = state_transition[7][qubitState];
    qubitState = collapse_it(qubitState);
    digitalWrite(8, HIGH);
    delay(1000);
    digitalWrite(8, LOW);
  }
}

//function that takes the current state and returns an int corresponding to new state.
//should be called in main qubitState = collapse_it(qubitState)
int collapse_it(int qubitState){
  coin = TCNT0 & 1;
  if(qubitState == -1){
    if(coin == 0){
      return 2;
    }
    else{
      return 3;
    }
  }
  if(qubitState == -2){
    if(coin == 0){
      return 4;
    }
    else{
      return 5;
    }
  }
  if(qubitState == -3){
    if(coin == 0){
      return 1;
    }
    else{
      return 0;
    }
  }
  return qubitState;
}

void detect_rotation(){
  int currentStateX = digitalRead(2);
  int currentStateY = digitalRead(0);
  int currentStateZ = digitalRead(7);
  if (currentStateX == HIGH && lastStateX == LOW) {
    x++;
  }
  lastStateX = currentStateX;
  
  if (currentStateY == HIGH && lastStateY == LOW) {
    y++;
  }
  lastStateY = currentStateY;
  
  if (currentStateZ == HIGH && lastStateZ == LOW) {
    z++;
  }
  lastStateZ = currentStateZ;
}

//function detects x gate and adjusts state accordingly
void detect_Xgate(){
 if(x == 5){
    qubitState = state_transition[1][qubitState];
    digitalWrite(8, HIGH);
    delay(1000);
    digitalWrite(8, LOW);
    x = 0;
  } 
}

//function detects y gate and adjusts state accordingly
void detect_Ygate(){
  if(y == 5){
    qubitState = state_transition[2][qubitState];
    digitalWrite(8, HIGH);
    delay(1000);
    digitalWrite(8, LOW);
    y= 0;
  }
}

//function detects z gate and adjusts state accordingly
void detect_Zgate(){
 if(z == 5){
    qubitState = state_transition[3][qubitState];
    digitalWrite(8, HIGH);
    delay(1000);
    digitalWrite(8, LOW);
    z = 0;
  }
}

void diode_output(int qubitState){
  digitalWrite(3, LOW);
  digitalWrite(9, LOW);
  digitalWrite(1, LOW);
  digitalWrite(6, LOW);
  digitalWrite(10, LOW);
  digitalWrite(11, LOW);
  switch (qubitState){
    case 0:
      digitalWrite(3, HIGH);
      break;
    case 1:
      digitalWrite(9, HIGH);
      break;
    case 2:
      digitalWrite(1, HIGH);
      break;
    case 3:
      digitalWrite(6, HIGH);
      break;
    case 4:
      digitalWrite(10, HIGH);
      break;
    case 5:
      digitalWrite(11, HIGH);
      break;
  }
}

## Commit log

2026-03-22 Dummy LED dimming example
2026-03-23 Rotary Encoder Signal Processing and Output Test
2026-03-23 Update STATE_TRANSITION.ino
    added measure x, y, z input buttons
2026-03-23 added output LEDs
2026-03-24 fixed duplicate measurement bug: now repeated measurement leaves the qubit unchanged
    [STATE_TRANSITION.ino]
2026-03-24 state transition table accidentally swapped z state when performing repeated z measurements
    [STATE_TRANSITION.ino]
2026-03-24 Here is the code for the logic of the score tracking, LCD display, timer, and audio output.
    The audio portion of the code is mainly placeholders, and it will be updated once we figure out the DFPlayer/whatever audio module we use.
2026-03-24 Hello World blinking LEDs for GitHub Assignment
2026-03-30 QUB-IT BOM
    [QUB-IT BOM - Sheet1.csv]
2026-03-31 Revise component quantities in BOM
    Updated quantities for various components in the BOM.
    [QUB-IT BOM - Sheet1.csv]
2026-03-31 Update component quantities
    [QUB-IT BOM - Sheet1.csv]
2026-04-25 Create CAD Files
2026-04-25 Rename QUB-IT BOM - Sheet1.csv to BOM/QUB-IT BOM - Sheet1.csv
    [QUB-IT BOM - Sheet1.csv]
